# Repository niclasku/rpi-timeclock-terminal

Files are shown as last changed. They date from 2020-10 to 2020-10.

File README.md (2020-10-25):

# rpi-timeclock-terminal
This is a python timeclock application running on a Raspberry Pi Zero W with attached touch screen
and RFID reader. It allows your employees to clock in/out and to see a summary of their worked 
hours and vacation. This project uses [bizley/timeclock](github.com/bizley/timeclock) as backend. 
Instructions on how to print the case and connect the hardware are in the ```hardware/``` folder.
 
## Operating System
Tested under [Raspbian](https://www.raspberrypi.org/downloads/raspbian/) Buster Lite February 2020.

## Dependencies
Update the system. 
```
sudo apt update
sudo apt dist-upgrade
```

Install dependencies and kivy.
```
sudo apt install libsdl2-dev libsdl2-image-dev libsdl2-mixer-dev libsdl2-ttf-dev \
   pkg-config libgl1-mesa-dev libgles2-mesa-dev \
   python-setuptools libgstreamer1.0-dev git-core \
   gstreamer1.0-plugins-{bad,base,good,ugly} \
   gstreamer1.0-{omx,alsa} python3-dev libmtdev-dev \
   xclip xsel libjpeg-dev python3-pip
sudo pip3 install Cython==0.29.10 pillow kivy pygments spidev pi-rc522 RPi.GPIO
```

## Configuration
Set locale and timezone.
```
sudo raspi-config
```

Modify ```/boot/config.txt``` to support touchscreen and RFID reader.
```
hdmi_group=2
hdmi_mode=87
hdmi_cvt 800 480 60 6 0 0 0
hdmi_drive=1
hdmi_force_hotplug=1
display_rotate=2
dtparam=i2c_arm=on
dtparam=spi=on
dtoverlay=ads7846,penirq=25,speed=10000,keep_vref_on=0,penirq_pull=2,xohms=150
dtoverlay=spi1-1cs
```

Modify kivy ```~/.kivy/config.ini``` to invert touchscreen x-axis (file is created during 
import of kivy).
```
[input]
mouse = mouse
%(name)s = probesysfs,provider=hidinput,param=invert_x=1
```

## Usage
Configuration is stored in ```config.py```. Currently supported languages: 'de', 'en'.
```
"""
Timeclock server address
"""
hostname = 'localhost'
port = '8000'

"""
Authorization of the timeclock's server special terminal user
"""
terminal_id = '4'
api_key = 'tRu4Y316ypP6Kfce4L4c'

"""
Locale has to be installed on the system
Languages currently supported: de, en
"""
locale = 'en_US.utf8'
lang = 'en'

"""
RFID device
/dev/spidevbus.device
e.g.: /dev/spidev1.0
irq = GPIO connected to interrupt pin RC522
rst = GPIO connected to reset pin RC522
"""
bus = 1
device = 0
irq = 36
rst = 37
```

The application downloads all user data from timeclock server automatically (pictures: only 283x420px tested).

Start application.
```
python3 terminal.py
```

## Autostart with systemd
Save to ```/etc/systemd/system/rpi-timeclock-terminal.service```:
```
[Unit]
Description=rpi-timeclock-terminal
After=network.target

[Service]
ExecStart=/usr/bin/python3 -u terminal.py
WorkingDirectory=/home/pi/rpi-timeclock-terminal
StandardOutput=inherit
StandardError=inherit
Restart=always
User=pi

[Install]
WantedBy=multi-user.target
```

Enable and start the service:
```
sudo systemctl enable rpi-timeclock-terminal.service
sudo systemctl start rpi-timeclock-terminal.service
```

## Automatic WiFi Reconnect
Sometimes the WiFi connection of the Pi dropped and new connection attempts failed. In order to address this issue one 
can use a watchdog that pings a local server and restarts the Pi if the server is not reachable. Installation:
```bash
sudo apt-get install watchdog
sudo modprobe bcm2835_wdt
echo "bcm2835_wdt" | sudo tee -a /etc/modules
```

Configuration file `/etc/watchdog.conf`.
```bash
realtime		= yes
priority		= 1

interface = wlan0    # use interface wlan0
ping-count = 5       # ping 5 times
ping = 192.168.1.1   # ping test destination IP address
interval = 50        # check interval
```

## Screenshots
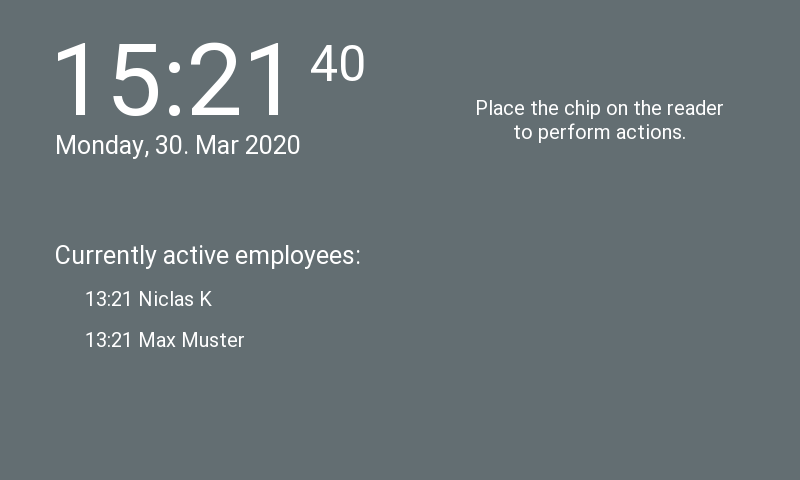
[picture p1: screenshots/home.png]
HomeScreen

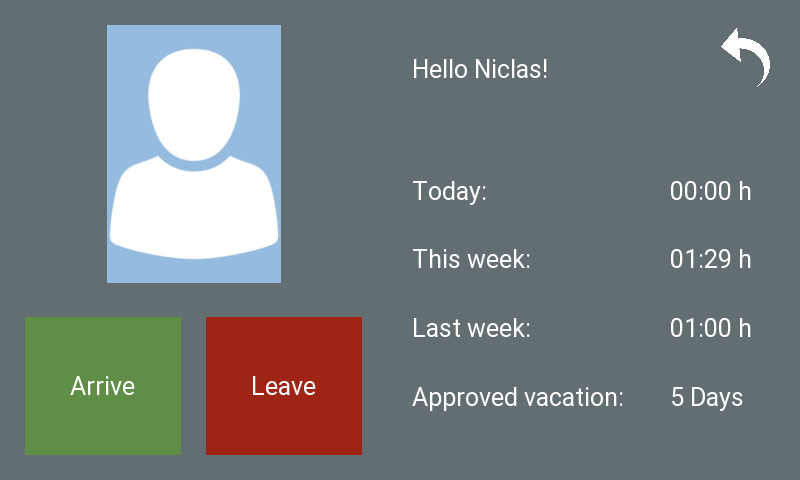
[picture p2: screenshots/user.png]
UserScreen

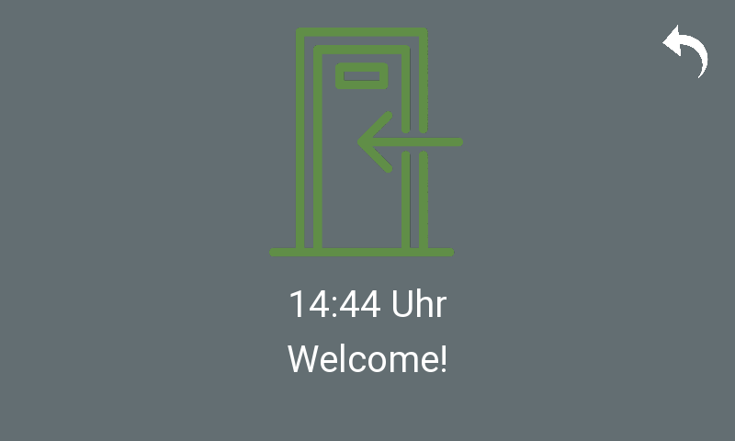
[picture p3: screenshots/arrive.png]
ClockInScreen

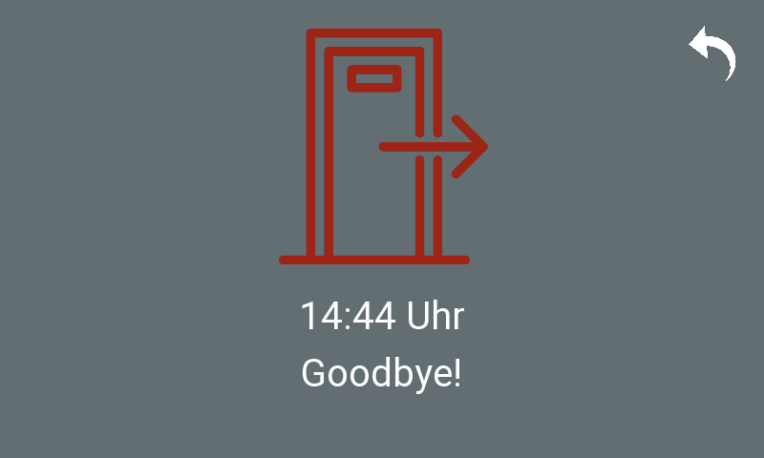
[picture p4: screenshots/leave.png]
ClockOutScreen

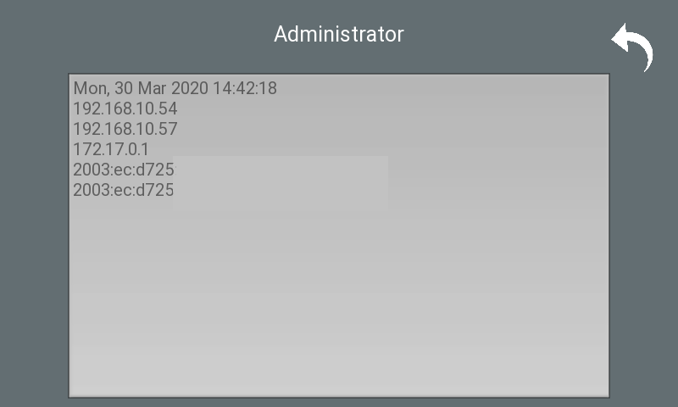
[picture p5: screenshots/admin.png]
AdminScreen

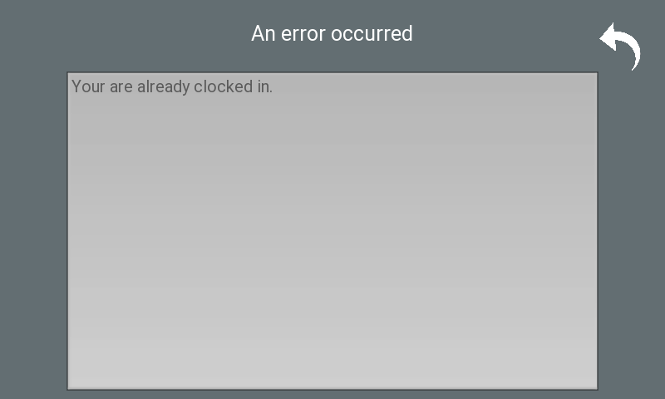
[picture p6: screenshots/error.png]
ErrorScreen


Photos of the hardware can be found in `hardware/` folder.

## Translations
Translations are in the ```lang/``` folder. You can use the following commands to initialize, update and
compile new translations (e.g 'de').
```
# Get translatable texts and create .pot file
xgettext -Lpython --from-code utf-8 --output=terminal.pot terminal.py terminal.kv dataprovider.py rfidprovider.py

# Initialize .po file
msginit --no-translator -o lang/de/LC_MESSAGES/terminal.po -i terminal.pot

# Update .po file
msgmerge --update --no-fuzzy-matching --backup=off lang/de/LC_MESSAGES/terminal.po terminal.pot

# Compile .po file
msgfmt -c -o lang/de/LC_MESSAGES/terminal.mo lang/de/LC_MESSAGES/terminal.po
```

## Colours
- Red 9E2416
- Green 608E47
- Orange CA5122
- Brown 9E7B53

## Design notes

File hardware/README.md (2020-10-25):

# Hardware
Used standard hardware combined with a 3D printed case.

## List
- [Waveshare 5 inch HDMI touchscreen](https://www.waveshare.com/wiki/5inch_HDMI_LCD)
- [Raspberry Pi Zero W](https://www.raspberrypi.org/products/raspberry-pi-zero-w/)
- RC522 RFID Module
- LM2596S DC/DC Converter
- [12V DC socket (2,1 x 5,5 mm M8)](https://www.segor.de/#Q=DCBU2%252C5%252F5%252C5Z-M8&M=1)
- 12V power supply

## Connecting
Touchscreen on SPI0

| Touchscreen | RPI Board Pin | Power Supply |
|---|---|---|
| 5V | - | 5V |
| GND | 6 | GND |
| MOSI | 19 | - |
| MISO | 21 | - |
| SCK | 23 | - |
| P6 | 22 | - |
| CE1 | 26 | - |
| HDMI | HDMI | - |

RC522 on SPI1

| RC522 | RPI Board Pin |
|---|---|
| SDA | 12 | 
| SCK | 40 | 
| MOSI | 38 | 
| MISO | 35 | 
| IRQ | 36 | 
| GND | 39 | 
| RST | 37 | 
| 3.3V | 1 |

## Case
You can 3D print a case. There is a ```front.stl```, ```back.stl```, ```spacer.stl``` (between screw and touchscreen) 
and ```rc522_holder.stl``` in the ```hardware/stl/``` folder. Settings for Ender 3:
```
Layer Height: 0.2mm
Wall thickness: 1.2mm
Infill: 50%
Speed: 50mm/s
```

Used Screws:
- [2.9 x 6.5 mm self-tapping screw](https://www.bauhaus.info/blech-metall-spenglerschrauben/stabilit-blechschraube/p/10775854)
- [3.5 x 9.5 mm self-tapping screw](https://www.bauhaus.info/blech-metall-spenglerschrauben/stabilit-blechschraube/p/10775892)

## Advices
1. LM2596S module failed and I replaced it with an external 5V 3A power supply.
2. Replaced thread screws of the case with self-tapping screws.

## Photos
TODO

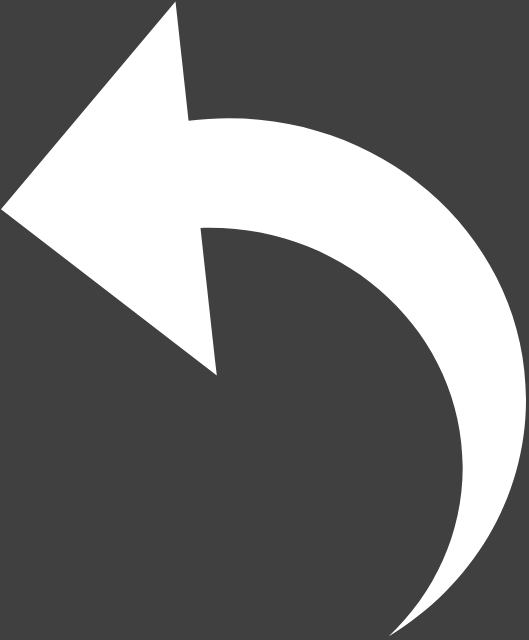
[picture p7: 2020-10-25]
images/back.png

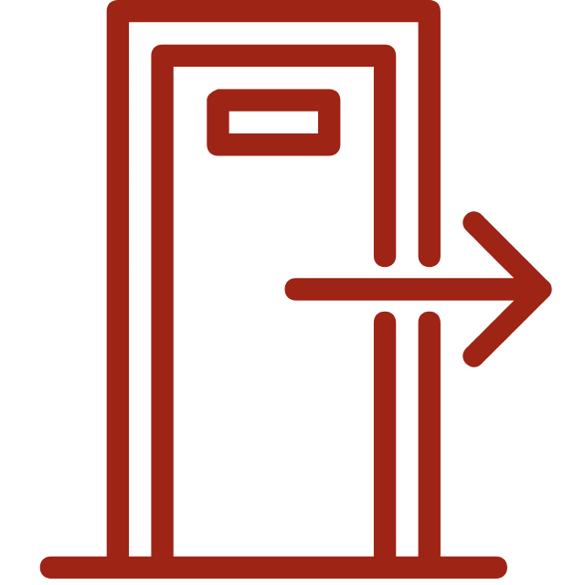
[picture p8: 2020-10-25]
images/clockout.png

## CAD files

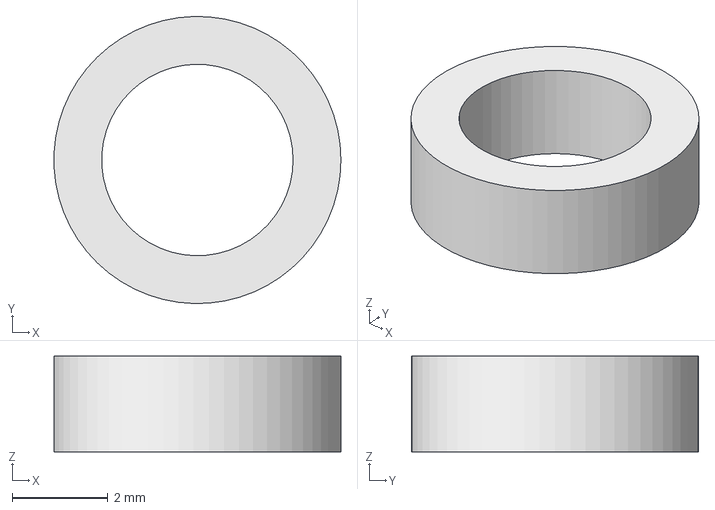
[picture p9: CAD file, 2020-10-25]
hardware/spacer.FCStd
6.00 x 6.00 x 2.00 mm

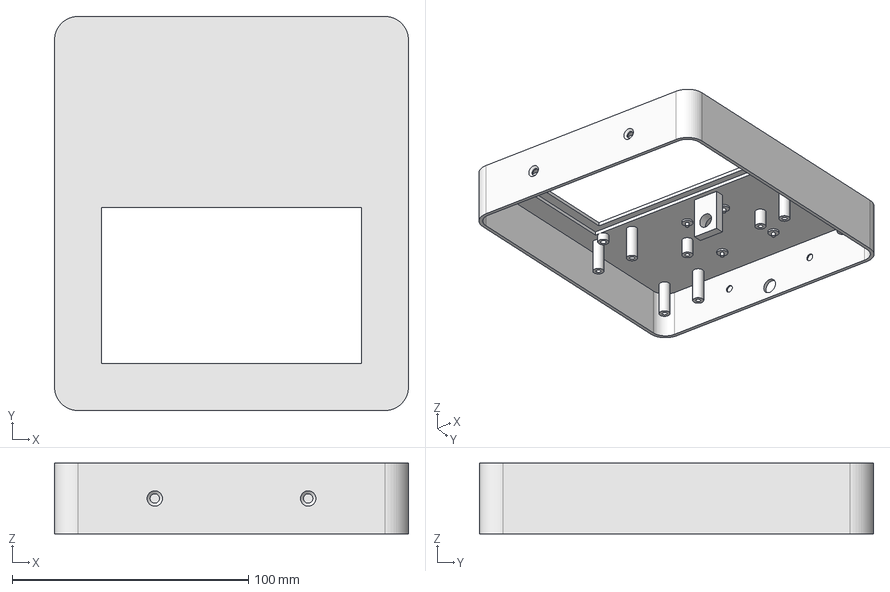
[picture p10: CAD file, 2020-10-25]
hardware/front.FCStd
150.0 x 167.0 x 30.0 mm

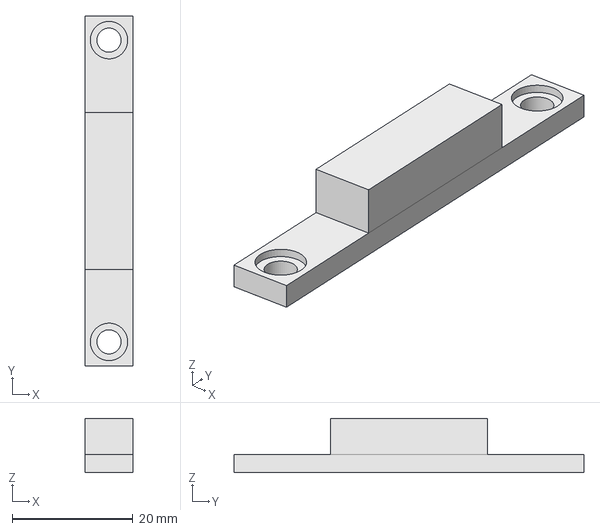
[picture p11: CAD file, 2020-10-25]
hardware/rc522_holder.FCStd
8.00 x 58.0 x 9.00 mm

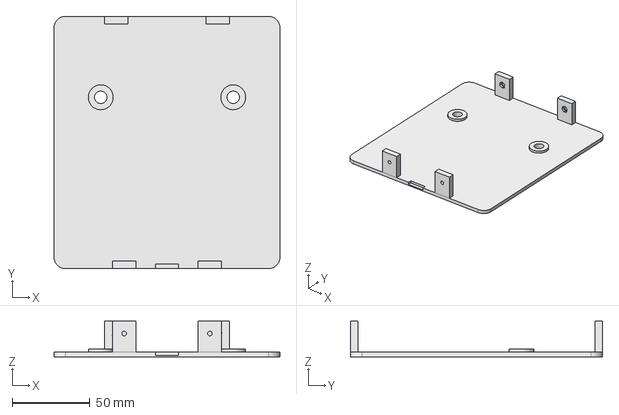
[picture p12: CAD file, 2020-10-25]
hardware/back.FCStd
145.0 x 162.0 x 23.0 mm

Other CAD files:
hardware/stl/back.stl
hardware/stl/front.stl
hardware/stl/rc522_holder.stl
hardware/stl/spacer.stl

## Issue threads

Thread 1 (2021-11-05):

RFID Enrollment

EngineControls, 2021-11-05:
Hi there i am using your project and your fork of the timeclock backend.

How do i set a RFID tag to a user?

Each time a present a RFID tag it says user does not exist: 10642181129116
Please can you explain the process to enroll users and set their RFID Tag.

niclasku, 2021-11-07:
Hi,
please log in as an admin in the timeclock web interface and click on/go to the "Employees" page. Then there should be a "Terminal" button for each employee. After clicking it, you'll see a form where you can set the RFID tag serial number and upload a picture.

If this doesn't work, please provide a little more information like screenshots. If it works, please let me know so I can close the issue.

Thanks!

EngineControls, 2021-11-08:
Hi there here is a screenshot of the screen, i do not see any terminal button available.
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

niclasku, 2021-11-08:
Are you sure you're using [my fork](https://github.com/niclasku/timeclock/) of the timeclock project? I don't see a link to the "Vacation" page in the menu but there should be one:

https://github.com/niclasku/timeclock/blob/278228ff8ff808f2678d3a3013dd67a822387e99/src/views/layouts/main.php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

EngineControls, 2021-11-08:
So from the raspberry pi i did a git clone https://github.com/niclasku/timeclock.git

niclasku, 2021-11-08:
That is the proper command, but according to the screenshot you are **not** using my fork. I guess you ran the composer command from my repo (`composer create-project --prefer-dist bizley/timeclock timeclock`) which (wrongly) pointed to the original repo, right? I just updated the install instructions (see [README](https://github.com/niclasku/timeclock/blob/master/README.md)). Please try to install and configure it again using the updated instructions.

EngineControls, 2021-11-08:
That is correct, i did run the composer create-project --prefer-dist bizley/timeclock timeclock command.

I will try the updated install instructions now and give you feedback.
Thank you so much for going out of your way to assist me, i really do appreciate it.

EngineControls, 2021-11-08:
I have followed the new instructions and i have managed to get it all to work. Thank you once again for assisting me :)

I have one last question the we can close this:

I am using the official 7inch touch screen and case https://www.raspberrypi.com/products/raspberry-pi-touch-display/ for this project but i cannot get the touch screen to work?

The touchscreen and everything works perfectly on the raspberry pi, desktop and all other applications.
But when the terminal autoload's or runs then the touchscreen does not work.

niclasku, 2021-11-08:
Nice :) I do not have an official rpi touchscreen, but as the timeclock terminal uses kivy this might help: https://kivy.org/doc/stable/installation/installation-rpi.html#using-official-rpi-touch-display

EngineControls, 2021-11-08:
Hi there everything is working thank you, you can close this :)

Thank you for all your help man.
Below i posted the changed to make the display work.

If you are using the official Raspberry Pi touch display, you need to configure Kivy to use it as an input source. To do this, edit the file ~/.kivy/config.ini and go to the [input] section. Add this:

mouse = mouse
mtdev_%(name)s = probesysfs,provider=mtdev
hid_%(name)s = probesysfs,provider=hidinput

Closed 2021-11-08.

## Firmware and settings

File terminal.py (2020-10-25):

import time
import locale
from os import popen
from threading import Thread
from gettext import translation

from kivy.app import App
from kivy import require
from kivy.clock import Clock
from kivy.config import Config
from kivy.logger import Logger
from kivy.properties import ObjectProperty, StringProperty

from kivy.uix.image import Image
from kivy.uix.label import Label
from kivy.uix.boxlayout import BoxLayout
from kivy.uix.stacklayout import StackLayout
from kivy.uix.behaviors import ButtonBehavior
from kivy.uix.screenmanager import ScreenManager, Screen

import config
from dataprovider import DataProvider
from rfidprovider import RfidProvider

require('1.11.1')


def _(*args):
    """
    Translator
    :param args: text to translate
    :return: translated text
    """
    return App.get_running_app().get_text(*args)


def change_screen(name, data=None):
    """
    Show another screen of the app
    :param name: name of the screen (terminal.kv)
    :param data: data to show on the selected screen
    :return: None
    """
    app = App.get_running_app()
    app.root.current = name
    if data:
        app.root.get_screen(name).show(data)


def show_user(tag):
    """
    Shows user info screen
    :param tag: serial number
    :return: None
    """
    change_screen('user', tag)


def show_error(message):
    """
    Shows error screen
    :param message: text to show
    :return: None
    """
    change_screen('error', message)


class CurrentWorkingWidget(StackLayout):
    """
    Shows the currently working employees in a table
    """

    def __init__(self, **kwargs):
        """
        Starts update thread every 15 seconds
        :param kwargs: kivy
        """
        super(CurrentWorkingWidget, self).__init__(**kwargs)
        self.widget_list = []
        self.worker = None
        Clock.schedule_interval(self.start_thread, 15)
        self.start_thread()

    def start_thread(self, *args):
        """
        Checks if update thread is running and starts it if not
        :param args: kivy
        :return: None
        """
        if self.worker and self.worker.is_alive():
            Logger.warning('Terminal: Update thread for working users is still running')
        else:
            self.worker = Thread(target=self.update_widgets)
            self.worker.start()

    def update_widgets(self, *args):
        """
        Update Label widgets without removing them (no flickering on RPI Zero W)
        by diffing current and new widgets. Adding and removing in main thread via
        kivy's schedule_once()
        :param args: kivy things
        :return: None
        """
        new_widgets = []
        working = dp.working_users()
        if len(working) > 0:
            for name, clock_in, user_id in working:
                if name is None:
                    name = _('Unknown ') + user_id
                item = Label(text_size=(250, 40), halign='left', font_size='20sp',
                             size_hint=(0.3, 0.01), text=clock_in + ' ' + name)
                new_widgets.append(item)

        remove = self.widget_list.copy()
        for old in self.widget_list:
            for new in new_widgets:
                if old.text == new.text:
                    remove.remove(old)

        add = new_widgets.copy()
        for new in new_widgets:
            for old in self.widget_list:
                if old.text == new.text:
                    add.remove(new)

        Clock.schedule_once(lambda x: self.remove_working_employees(remove), 0)
        Clock.schedule_once(lambda x: self.add_working_employees(add), 0)

    def add_working_employees(self, items):
        """
        Adds labels to table and to internal list
        :param items: labels
        :return: None
        """
        for item in items:
            self.add_widget(item)
            self.widget_list.append(item)

    def remove_working_employees(self, items):
        """
        Removes labels from table and from internal list
        :param items: labels
        :return: None
        """
        for item in items:
            self.remove_widget(item)
            self.widget_list.remove(item)


class ClockWidget(ButtonBehavior, BoxLayout):
    """
    Home screen clock
    """
    hours_minutes = StringProperty()
    seconds = StringProperty()
    date_string = StringProperty()

    def __init__(self, **kwargs):
        """
        Schedules clock update for every second
        :param kwargs: kivy
        """
        super(ClockWidget, self).__init__(**kwargs)
        Clock.schedule_interval(self.update_time, 1)
        self.update_time()
        self.press_time = time.time()
        self.press_counter = 0

    def update_time(self, *args):
        """
        Updates current time
        :param args: kivy
        :return: None
        """
        self.hours_minutes = time.strftime('%H:%M', time.localtime())
        self.seconds = time.strftime('%S', time.localtime())
        self.date_string = time.strftime('%A, %d. %b %Y', time.localtime())

    def on_press(self):
        """
        Hidden admin screen, press 3 times in 5 seconds to get there
        :return: None
        """
        current_time = time.time()
        if current_time - self.press_time < 5:
            self.press_counter += 1
            if self.press_counter == 3:
                self.press_counter = 0
                change_screen('admin', None)
        else:
            self.press_counter = 1
            self.press_time = time.time()


class BackButton(ButtonBehavior, Image):
    pass


class HomeScreen(Screen):
    """
    Home screen with clock and currently working employees
    """
    current_working = ObjectProperty()

    def __init__(self, **kwargs):
        super(HomeScreen, self).__init__(**kwargs)
        self.worker = None

    def on_enter(self, *args):
        """
        Starts thread that waits for a RFID tag
        :param args: kivy
        :return: None
        """
        if self.worker and self.worker.is_alive():
            Logger.warning('Terminal: Rfid worker thread not exited correctly (coming from admin screen?)')
        else:
            self.worker = Thread(target=self.read_rfid_tag, daemon=True)
            self.worker.start()

    def read_rfid_tag(self, *args):
        """
        Thread waiting for RFID tag, updates UI in main thread
        :param args: kivy
        :return: None
        """
        uid = rp.read_uid()
        if not uid or self.manager.current != 'home':
            return
        Clock.schedule_once(lambda x: show_user(uid), 0)


class UserScreen(Screen):
    """
    User screen with image, info about worked hours and arrive/leave buttons
    """
    welcome = StringProperty()
    today_hours = StringProperty()
    week_hours = StringProperty()
    last_week_hours = StringProperty()
    holidays = StringProperty()
    user_image = StringProperty()

    def __init__(self, **kwargs):
        super(UserScreen, self).__init__(**kwargs)
        self.user_id = None
        self.worker = None

    def show(self, tag):
        """
        Updates properties with current user data and
        starts thread to load info about worked hours later
        :param tag: serial number
        :return: None
        """
        self.today_hours = ''
        self.week_hours = ''
        self.last_week_hours = ''
        self.holidays = ''

        resp = dp.user_info(tag)
        if not resp:
            show_error(_('User does not exist: ') + str(tag))
            return

        self.welcome = _('Hello ') + resp[0].split(' ')[0] + '!'
        self.user_image = resp[1]
        self.user_id = resp[2]

        if self.worker and self.worker.is_alive():
            Logger.error('Terminal: Get user data thread is still running')
        else:
            self.worker = Thread(target=self.get_data, daemon=True)
            self.worker.start()

    def get_data(self):
        """
        Retrieves info about worked hours, update of UI in main thread
        :return: None
        """
        resp = None
        if self.user_id:
            resp = dp.user_work_summary(self.user_id)
        if not resp:
            return
        Clock.schedule_once(lambda x: self.update_user_data(resp), 0)

    def update_user_data(self, data):
        """
        Updates UI with given data
        :param data: array with worked minutes and vacation days
        :return: None
        """
        self.today_hours = "{:02d}".format(int(data[0] / 60)) + ':' + "{:02d}".format(data[0] % 60) + ' h'
        self.week_hours = "{:02d}".format(int(data[1] / 60)) + ':' + "{:02d}".format(data[1] % 60) + ' h'
        self.last_week_hours = "{:02d}".format(int(data[2] / 60)) + ':' + "{:02d}".format(data[2] % 60) + ' h'
        self.holidays = str(data[3]) + _(' Days')

    def clock_in(self):
        """
        Clocks in user and shows error or welcome/goodbye screen
        :return: None
        """
        if self.user_id:
            ret = dp.clock_in(self.user_id)
            if ret:
                change_screen('clock')
                screen = self.parent.get_screen('clock')
                screen.show(True)
            elif ret is False:
                show_error(_('Your are already clocked in.'))
            else:
                show_error(_('Server error. Could not clock in user. ID: ') + str(self.user_id))
        else:
            Logger.error('Terminal: no user id set to clock in')

    def clock_out(self):
        """
        Clocks out user and shows error or welcome/goodbye screen
        :return: None
        """
        if self.user_id:
            ret = dp.clock_out(self.user_id)
            if ret:
                change_screen('clock')
                screen = self.parent.get_screen('clock')
                screen.show(False)
            elif ret is False:
                show_error(_('Your are already clocked out.'))
            else:
                show_error(_('Server error. Could not clock out user. ID: ') + str(self.user_id))
        else:
            Logger.error('Terminal: no user id set to clock out')


class ClockInOutScreen(Screen):
    """
    Welcome and goodbye screen
    """
    current_time = StringProperty()
    message = StringProperty()
    image = StringProperty()

    def __init__(self, **kwargs):
        super(ClockInOutScreen, self).__init__(**kwargs)
        self.timer = None

    def back(self):
        """
        Back button, cancels automatic back
        :return: None
        """
        if self.timer:
            self.timer.cancel()
        change_screen('home')

    def show(self, clock_in):
        """
        Shows Welcome/Goodbye message with door image and
        starts timer to go back after 3 seconds
        :param clock_in: True if user clocked in
        :return: None
        """
        self.current_time = time.strftime('%H:%M Uhr', time.localtime())
        if clock_in:
            self.image = 'images/clockin.png'
            self.message = _('Welcome!')
        else:
            self.image = 'images/clockout.png'
            self.message = _('Goodbye!')
        App.get_running_app().root.get_screen('home').current_working.start_thread()
        self.timer = Clock.schedule_once(lambda x: change_screen('home'), 3)


class ErrorScreen(Screen):
    message = StringProperty()

    def show(self, message):
        """
        Shows error message
        :param message: error message
        :return: None
        """
        self.message = message

    @staticmethod
    def back():
        """
        Back button
        :return: None
        """
        change_screen('home')


class AdminScreen(Screen):
    message = StringProperty()

    def on_enter(self, *args):
        """
        Shows time and all IP addresses
        :param args: kivy
        :return: None
        """
        t = time.strftime("%a, %d %b %Y %H:%M:%S")
        ips = popen('hostname -I').read().split(' ')
        i = '\n'.join(ips)
        self.message = t + '\n' + i

    @staticmethod
    def back():
        """
        Back button
        :return: None
        """
        change_screen('home')


class GlobalScreenManager(ScreenManager):
    """
    Manager for different screens
    """

    @staticmethod
    def build():
        return ScreenManager()


class Terminal(App):
    """
    Main app
    """

    def __init__(self, lang):
        """
        Initializes kivy app and sets language
        :param lang: supported language e.g. 'de'
        """
        super().__init__()
        self.lang = translation('terminal', localedir='lang', languages=[lang], fallback=True)

    def build(self):
        """
        Sets window settings and starts ScreenManager with first screen (home)
        :return: GlobalScreenManager
        """
        # set configuration
        Config.set('graphics', 'resizable', False)
        Config.set('graphics', 'borderless', True)
        Config.set('graphics', 'height', 480)
        Config.set('graphics', 'width', 800)
        Config.set('graphics', 'show_cursor', '0')
        locale.setlocale(locale.LC_ALL, config.locale)

        return GlobalScreenManager()

    def on_stop(self):
        """
        Graceful exit
        :return: None
        """
        Logger.info('Terminal: GPIO cleanup and exit')
        rp.cleanup()

    def get_text(self, *args):
        """
        Translation
        :param args: text
        :return: translated text
        """
        return self.lang.gettext(*args)


if __name__ == '__main__':
    try:
        dp = DataProvider(config.hostname, config.port, config.terminal_id, config.api_key)
        rp = RfidProvider(config.bus, config.device, config.irq, config.rst)
        Terminal(config.lang).run()
    except KeyboardInterrupt:
        App.get_running_app().stop()

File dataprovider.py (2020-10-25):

from time import time
from hashlib import sha1
from kivy.logger import Logger
from requests import get, post
from datetime import datetime


class DataProvider:

    def __init__(self, host, port, terminal_id, auth):
        """
        Provides data taken from timeclock server
        :param host: IP address or hostname
        :param port: port number
        :param terminal_id: identifier of terminal user
        :param auth: authentication token of terminal user
        """
        self.host = host
        self.port = port
        self.terminal_id = terminal_id
        self.auth = auth
        self.employees = []
        self.last_update = 0
        self.__update_employees()

    def __update_employees(self):
        try:
            update = int(self.__get('update')['updated_at'])
            if self.last_update < update:
                self.last_update = update
                data = self.__get('users')
                for user in data:
                    image = 'data/empty.jpg'
                    if user['image']:
                        image = 'data/' + user['image']
                        self.__download_image(user['id'], 'data/' + user['image'])
                    self.employees.append({
                        'id': str(user['id']),
                        'name': user['name'],
                        'tag': user['tag'],
                        'picture': image
                    })
        except Exception as e:
            Logger.error('DataProvider: ' + str(e))

    def __get_user_data(self, desc, value):
        for item in self.employees:
            if item[desc] == value:
                return item
        return None

    def __header(self):
        timestamp = str(int(time()))
        sha = sha1()
        sha.update((timestamp + self.auth).encode('utf-8'))
        token = sha.hexdigest()
        return {'Authorization': 'Bearer ' + self.terminal_id + ':' + timestamp + ':' + token}

    def __url(self, endpoint):
        return 'http://' + self.host + ':' + self.port + '/api/terminal/' + endpoint

    def __get(self, endpoint, data=None):
        resp = get(self.__url(endpoint), headers=self.__header(), json=data)
        return resp.json()

    def __post(self, endpoint, data):
        return post(self.__url(endpoint), headers=self.__header(), json=data).json()

    def __download_image(self, user_id, path):
        resp = get(self.__url('image'), headers=self.__header(), json={'user_id': user_id})
        with open(path, 'wb') as file:
            file.write(resp.content)

    def user_info(self, tag):
        """
        Returns user data
        :param tag: rfid tag identifier
        :return: None or (name, picture path, user_id)
        """
        data = self.__get_user_data('tag', tag)
        if data:
            return data['name'], data['picture'], data['id']

    def user_work_summary(self, user_id):
        """
        Gets work summary from timeclock server
        :param user_id: identifier of timeclock user
        :return: None or (today, week, last_week, vacation)
        """
        try:
            data = self.__get('summary', {'user_id': user_id})
            return int(round(data['today'] / 60)), int(round(data['this_week'] / 60)), \
                   int(round(data['last_week'] / 60)), int(data['vacation'])
        except Exception as e:
            Logger.error('DataProvider: ' + str(e))
            return None

    def clock_in(self, user_id):
        """
        Clocks in user
        :param user_id: identifier of timeclock user
        :return: True if successful, False if already clocked in, None if error
        """
        try:
            if self.__post('in', {'user_id': user_id}) == True:
                return True
            else:
                return None
        except Exception as e:
            Logger.error('DataProvider: ' + str(e))
            return None

    def clock_out(self, user_id):
        """
        Clocks out user
        :param user_id: identifier of timeclock user
        :return: True if successful, False if not clocked in, None if error
        """
        try:
            if self.__post('out', {'user_id': user_id}) == True:
                return True
            else:
                return None
        except Exception as e:
            Logger.error('DataProvider: ' + str(e))
            return None

    def working_users(self):
        """
        Returns list of clocked in users
        :return: list of tuples (name, start, user_id)
        """
        # check if employee list needs an update (ugly)
        self.__update_employees()
        user_id_list = []
        try:
            data = self.__get('working')
            for item in data:
                name = None
                user = self.__get_user_data('id', str(item['user_id']))
                if user:
                    name = user['name']
                start = datetime.fromtimestamp(item['clock_in']).strftime('%H:%M')
                user_id_list.append((name, start, str(item['user_id'])))
        except Exception as e:
            Logger.error('DataProvider: ' + str(e))
        return user_id_list
